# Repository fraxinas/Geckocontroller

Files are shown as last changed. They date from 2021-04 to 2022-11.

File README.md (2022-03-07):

# Geckocontroller

(CC) 2021-2022 by Andreas Frisch <github@fraxinas.dev>

## OwO what's this?
**`geckocontroller` is an ESP32-based all-in-one solution for terrarium automation.**

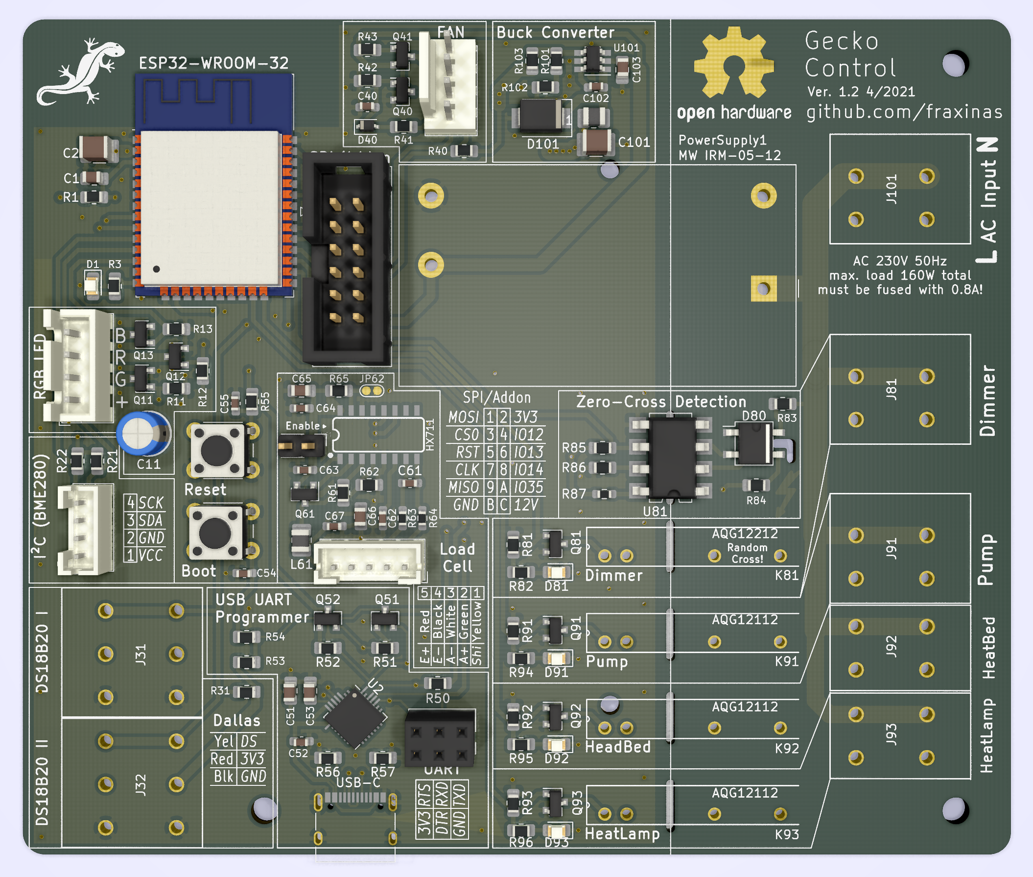
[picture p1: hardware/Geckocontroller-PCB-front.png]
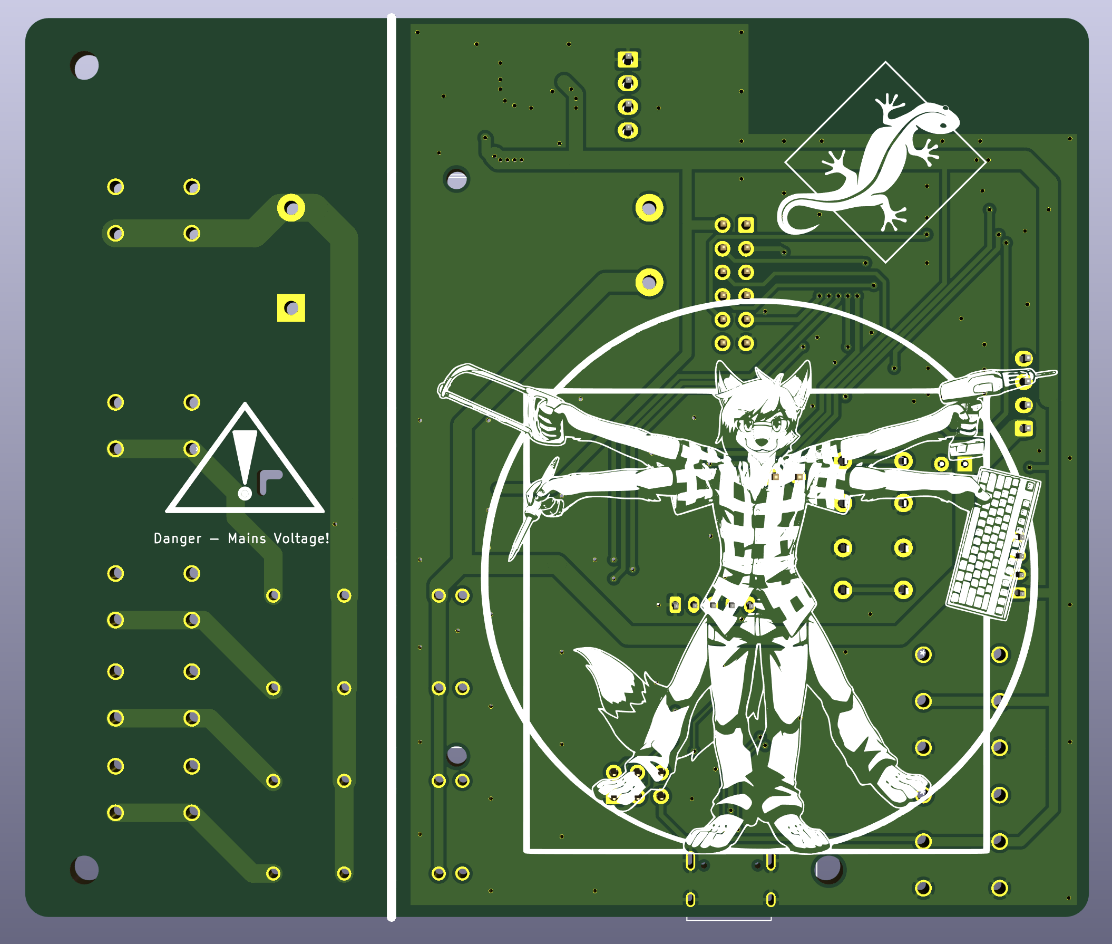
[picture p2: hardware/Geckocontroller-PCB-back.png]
|  |  |
| :--- | :--- |

## Hardware Features
### Relay Output
* 3 solid state relays with zero-cross switching
* individual load 1A each
* for HeatBed (/Fogger), HeatLamp and Pump

### Dimmer Output
* opto-coupler zero cross detection
* random cross solid state relay
* phase controller modulator

### RGB LED Output
* PWM driver
* for 12V RGB LED stripes

### FAN Output
* for an ATX type PC fan
* PWM and tachometer pins
* power cut-off circuitry for completely stopping all types of fans

### Dallas Thermometer Input
* 2 inputs for DS18B20 bus temperature sensors

### I²C Ports
* BME280 Thermo/Hygro/Baro sensor module (ceiling)
* SHT-3xD Thermo/Hygro sensor (ground)

### Load Cell Input
* HX711-based load cell amplifier/ADC
* for weighing / occupancy detection

### USB-C Port
* USB-to-serial programming port

### WiFi
* ESP32 wifi client

### SPI / Addon Connector
* for future extensions like a display or console

### Documentation
* [Circuit Calculations](hardware/calculations/README.md)

## Software

### Using ESPHome.io
* simple YAML configuration for different sensor / actor modules
* Through Home Assistant web interface:
  * data logging and visualization of all environmental readings
  * manually control all actors, modify set points of controllers

### Weather Simulation
* use Nouvelle-Calédonie (Crested Gecko's natural habitat) real weather records
* use temperature, humidity, rain and sky cover values for creating a realistic varied simulation of the habitants' indigenous environment
* simulated sunrise, sunset, lightening storm

### Documentation
* [How-to Setup & Calibrate](software/README.md)

## Console unit
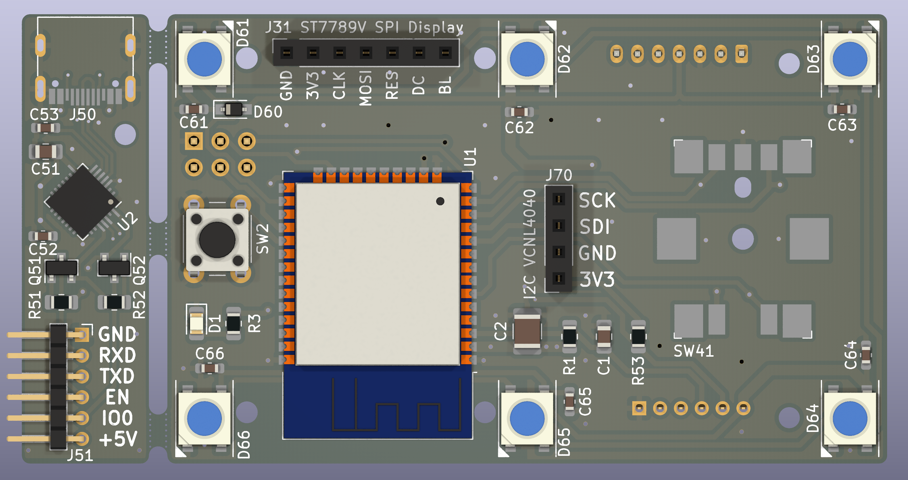
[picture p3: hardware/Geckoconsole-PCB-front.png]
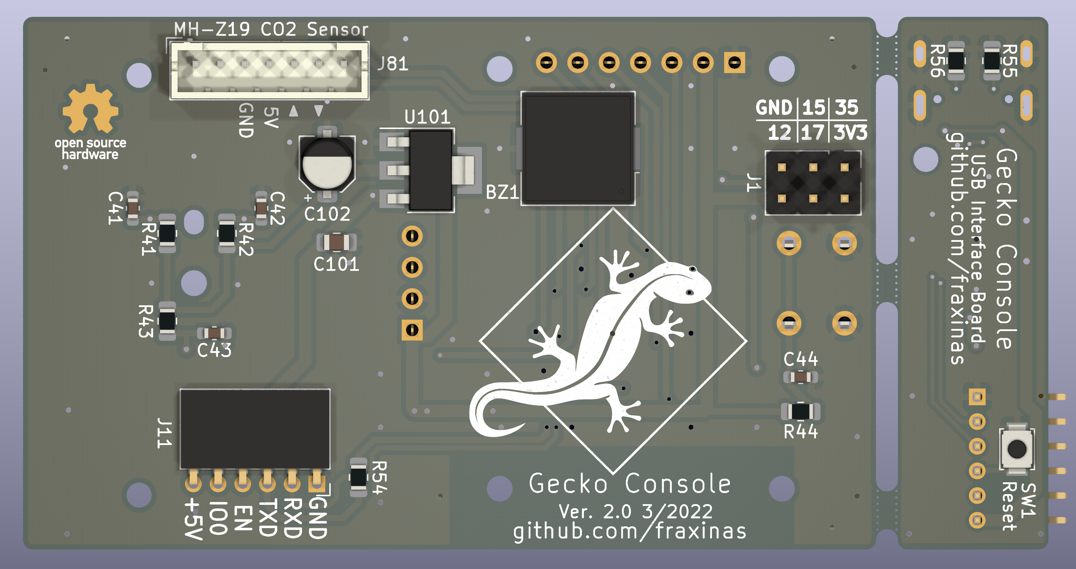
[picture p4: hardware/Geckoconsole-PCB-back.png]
|  |  |
| :--- | :--- |
* Stand-alone device based on ESP32
* remote controls the main unit through home assistant via WiFi
* 240x240 IPS Display
* Rotary encoder + navigation button
* MH-Z19 CO<sub>2</sub> Sensor
* 6x WS2812 addressable RGB LEDs
* Piezo Buzzer for audio alerts
* USB-C powered
* custom esphome components:
  * controls for thermostat, hygrostat, rain, fogger
  * HSV color picker for scenic light

## TODO
### Console unit
- [X] schematic & PCB layout
- [ ] 3d case
- [X] CO2 sensor
- [X] WS2812 RGB LEDs
- [X] buzzer
- [X] software for ST7789 display
- [X] software for rotary encoder
- [ ] VCNL4040 support
- [ ] photos / documentation

### Controller unit
- [x] 3d-printed cases for BME280 sensor and console
- [x] rainfall/humidity automation
- [x] ventilation automation
- [x] moonlight simulation
- [x] thunderstorm simulation
- [ ] photos / documentation

## Project Diary
| Date | Version | Milestone |
| :--- | :--- | :--- |
| 2021-02-21 | v1.0 | Commission of 1st prototype PCB with aisler.net  |
| 2021-03-12 | v1.1 | First time programming of bodged prototype PCB |
| 2021-04-10 | | Fixed hardware issues with [LeoDJ](https://github.com/LeoDJ) & [Patagona](https://github.com/patagonaa) |
| 2021-04-15 | v1.2 | Commission of 2nd revision PCB with aisler.net |
| 2021-05-03 | v1.2 | Completed PCB assembly, all modules working |
| 2021-05-16 | v1.2 | Assembling of case and first deployment of unit  |
| 2022-01-02 | | Added fogger to terrarium |
| 2022-01-09 | | Base weather simulation on real historic records |
| 2022-01-28 | v1.0 | Order Console PCB at aisler.net & parts at LCSC  |
| 2022-02-18 | | Assembled Console PCB |
| 2022-03-07 | v2.0 | New Hardware Revision of Console PCB |

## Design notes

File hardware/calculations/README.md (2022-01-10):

# Geckocontroller Hardware

## Calculations

### ACT4088 Feedback Resistors

with
* V<sub>out</sub> = 3.3V
* R<sub>FB1</sub> chosen 47k

* R<sub>FB2</sub> = R<sub>FB1</sub> / ((V<sub>out</sub> / 0.81) - 1) = 15289.156626506

Values are:
* `R103` = 47k
* `R101` = 15k
* `R102` = 287R

### HX711 Reference Voltage Resistors

with
* AVDD should be 100mV below VCC, so 3.20V
* AVDD = V<sub>BG</sub> * ( R1 + R2 ) / R2
* R1 chosen 47k

Values are:
* `R61` = 47k
* `R62` = 30k1

### FAN PWM integrator switching
* usually PWM fans can't be reliably attenuated to 0 rpm and need to have their Vcc switched in order to turn them off completely
* so to save one extra GPIO output for switching the fan power, this circuit will integrate the PWM signal and simply disconnect the fan's 12V power if the PWM duty cycle is near 0

http://www.falstad.com/circuit/circuitjs.html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

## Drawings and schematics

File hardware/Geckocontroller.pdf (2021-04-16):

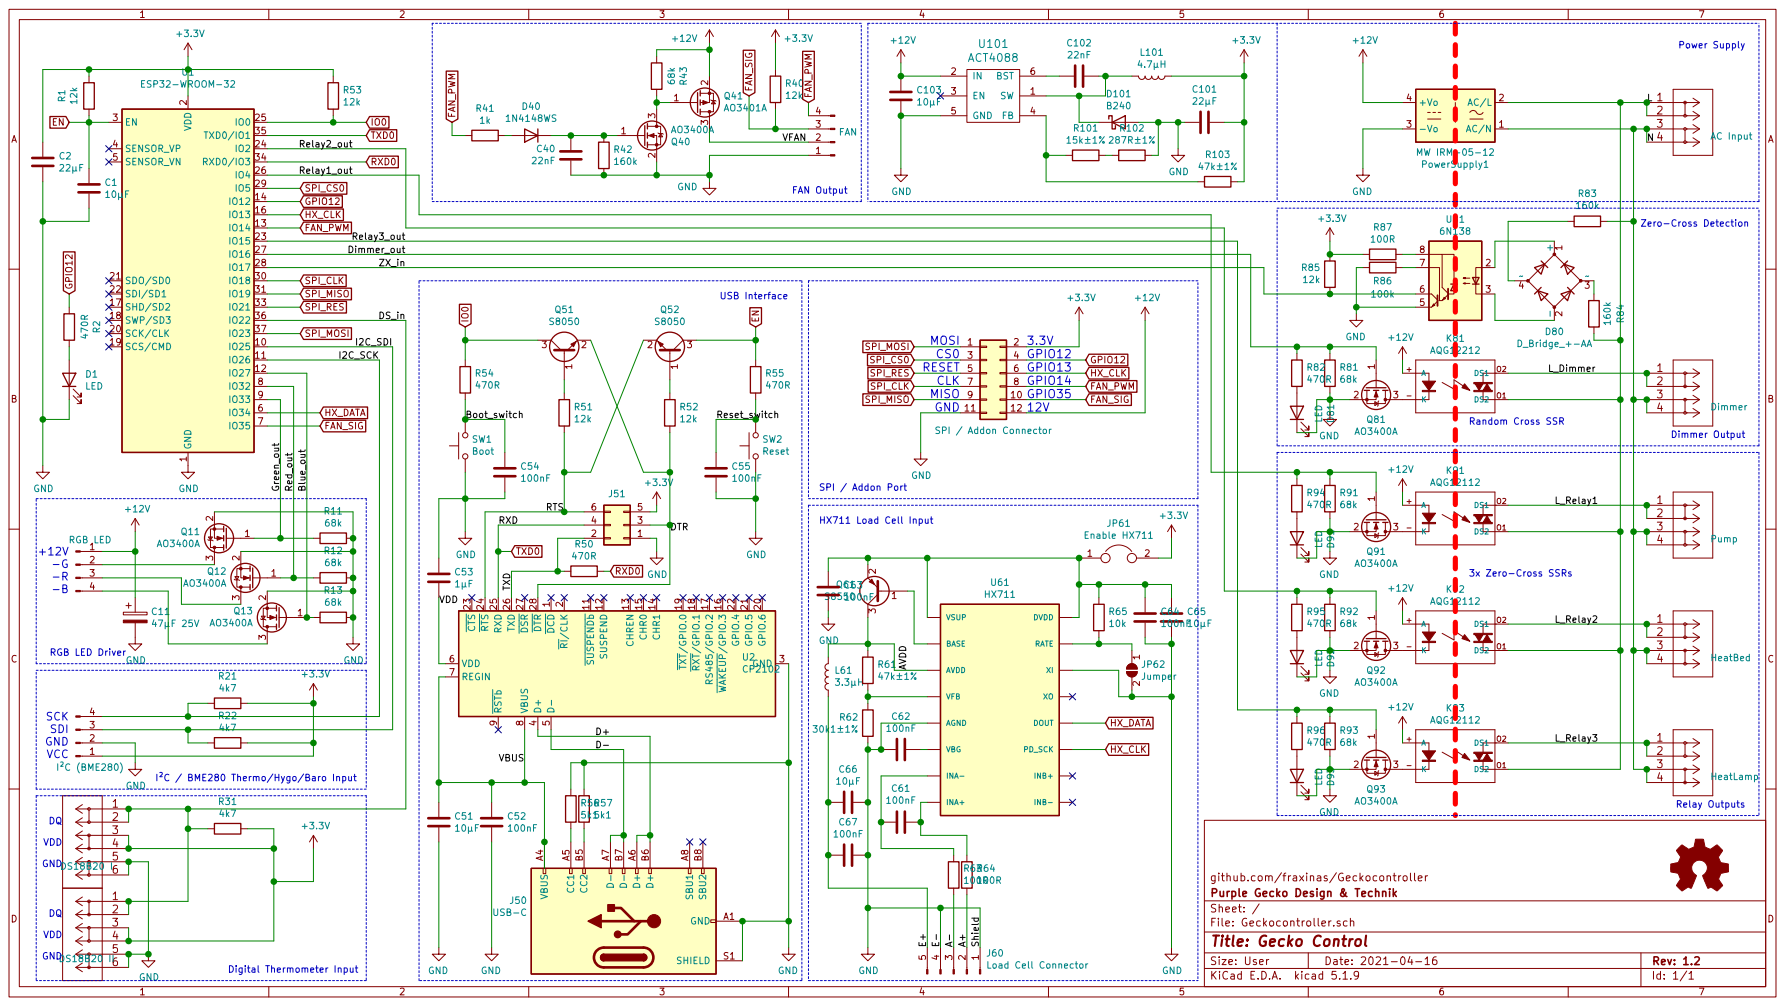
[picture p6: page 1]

2 SCK/CLK 20 SDO/SD0 21 SDI/SD1 22

L_Dimmer Digital Thermometer Input DQ

github.com/fraxinas/Geckocontroller LED D91

Dimmer Output 3x Zero-Cross SSRs

I²C / BME280 Thermo/Hygo/Baro Input +12V

2 GPIO.6 20 GPIO.5 21 GPIO.4 22 CTS 23 RTS 24 RXD 25 TXD 26 DSR 27 DTR 28 GND 3 D+

1 SUSPENDb 11 SUSPEND 12 CHREN 13 CHR1 14 CHR0 15 WAKEUP/GPIO.3 16 RS485/GPIO.2 17 RXT/GPIO.1 18 TXT/GPIO.0 19 RI/CLK

RGB LED Driver SCK

Load Cell Connector AGND

Id: 1/1 Title: Gecko Control File: Geckocontroller.sch Sheet: / Purple Gecko Design & Technik

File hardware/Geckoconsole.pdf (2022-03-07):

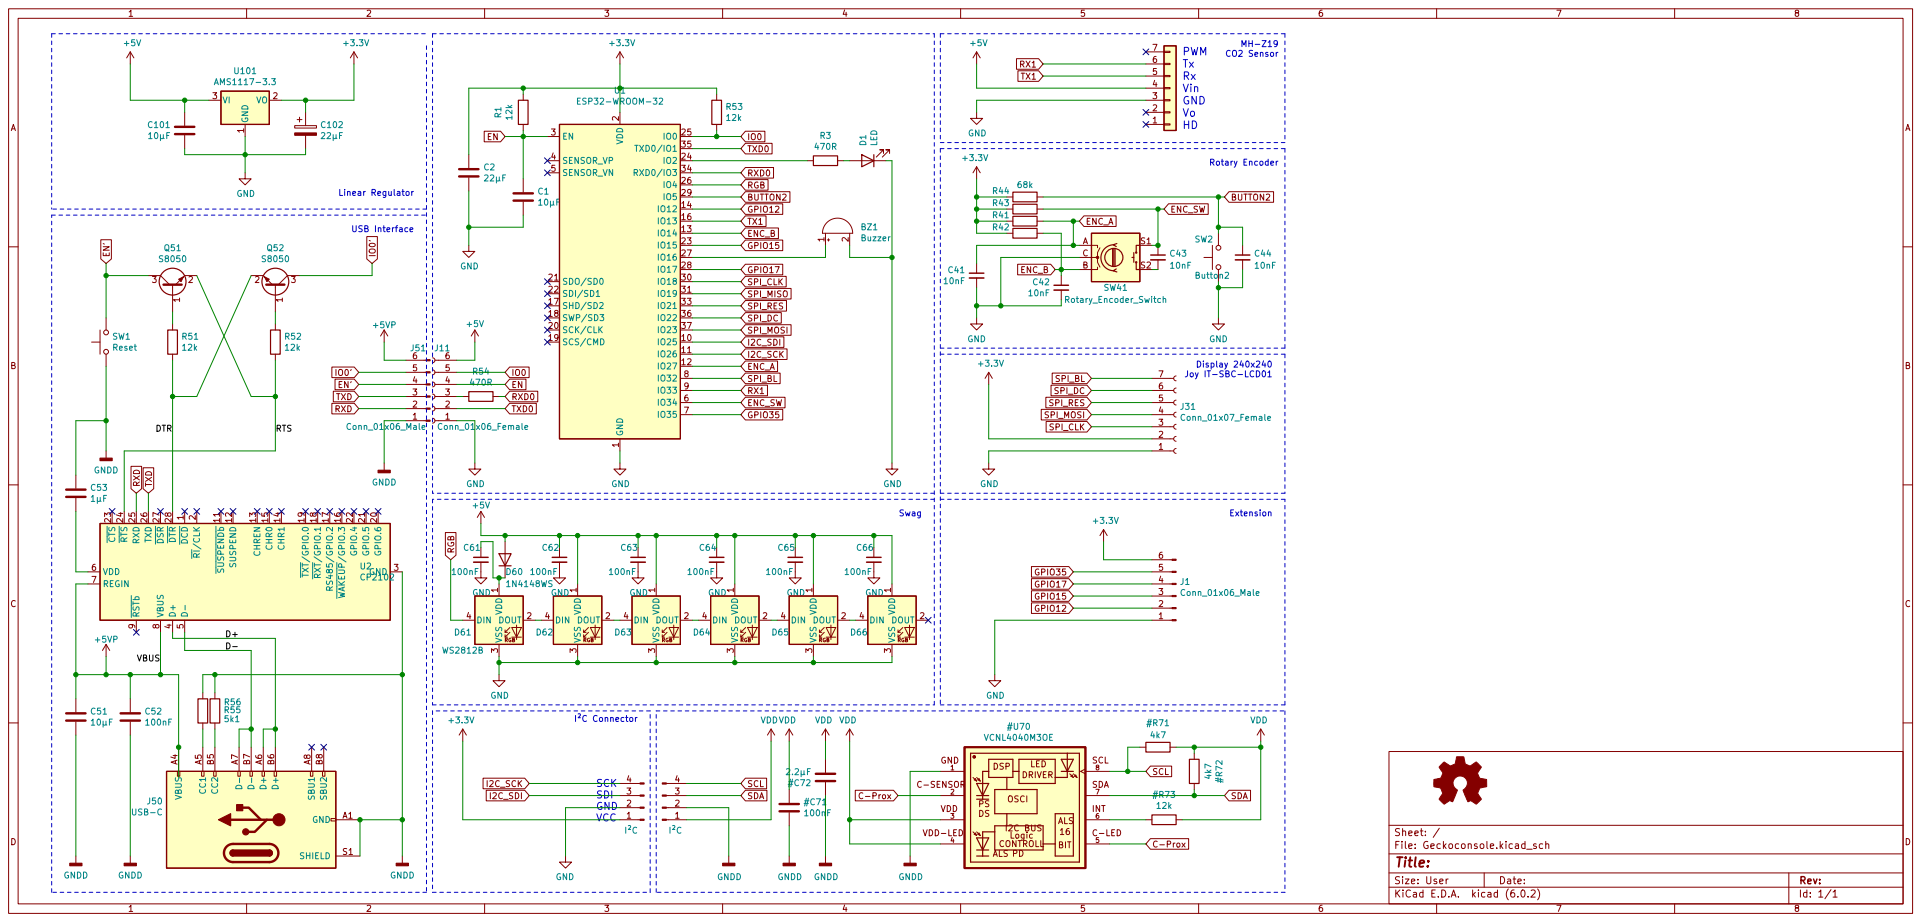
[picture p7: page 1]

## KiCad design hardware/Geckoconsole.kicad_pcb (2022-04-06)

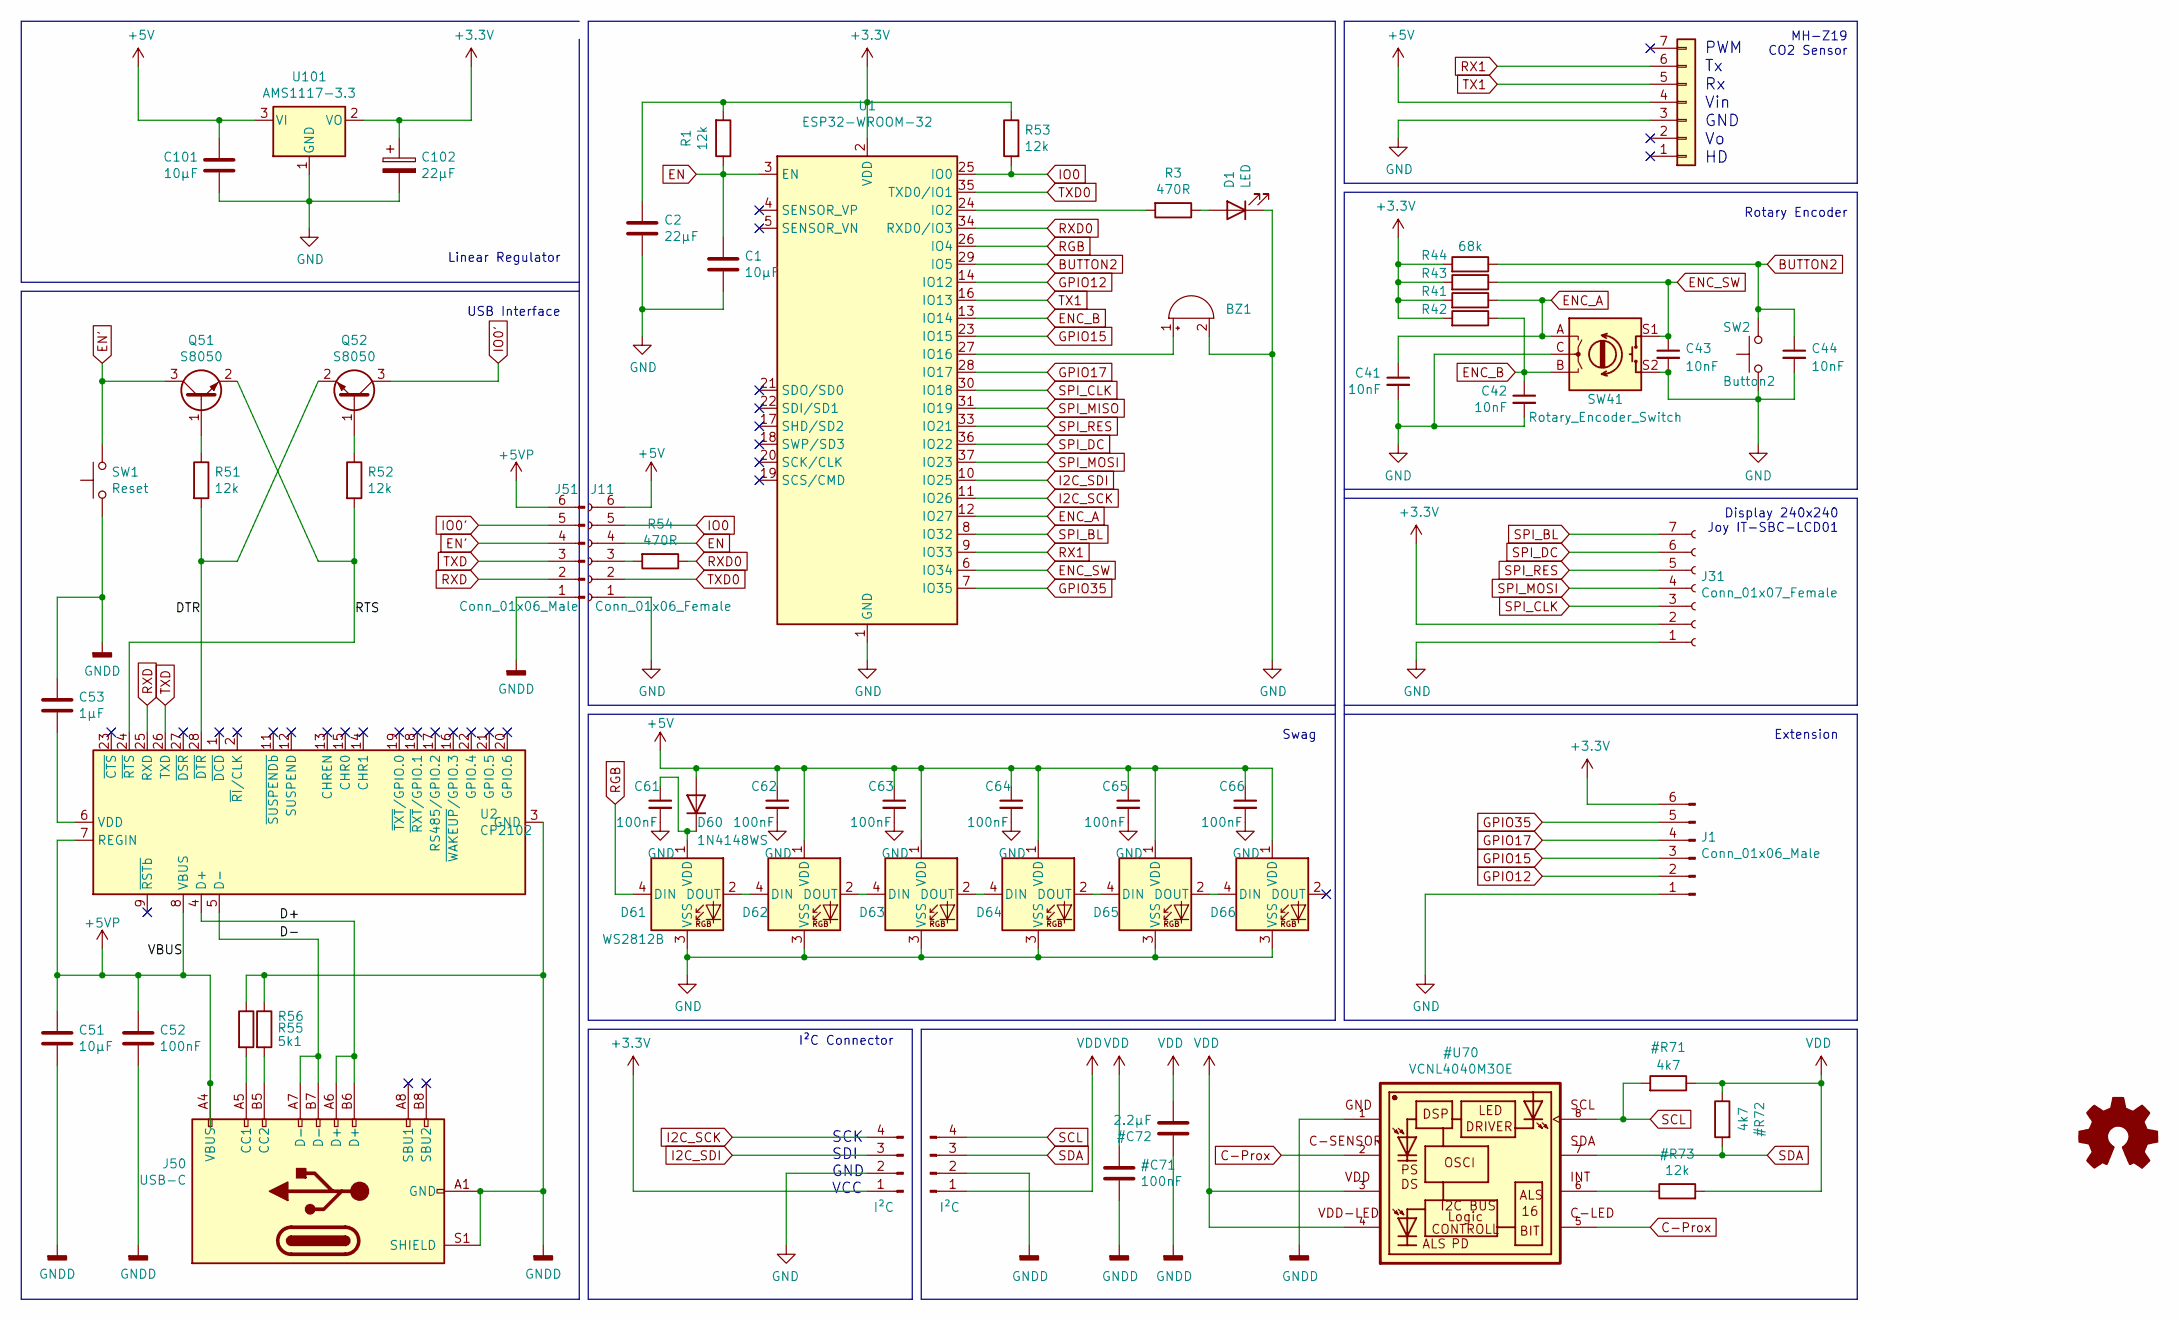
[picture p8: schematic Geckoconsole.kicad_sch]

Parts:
BZ1: (no value)
C1, C51, C101: 10µF; C_0805_2012Metric_Pad1.18x1.45mm_HandSolder
C2: 22µF; C_1210_3225Metric_Pad1.33x2.70mm_HandSolder
C41, C42, C43, C44: 10nF; C_0603_1608Metric_Pad1.08x0.95mm_HandSolder
C52, C61, C62, C63, C64, C65, C66: 100nF; C_0603_1608Metric_Pad1.08x0.95mm_HandSolder
C53: 1µF; C_0603_1608Metric_Pad1.08x0.95mm_HandSolder
C102: 22µF; CP_Elec_4x5.3
D1: LED; LED_0805_2012Metric_Pad1.15x1.40mm_HandSolder
D60: 1N4148WS; D_SOD-323_HandSoldering
D61, D62, D63, D64, D65, D66: WS2812B; LED_WS2812B_PLCC4_5.0x5.0mm_P3.2mm_Marking
J1: Conn_01x06_Male; PinHeader_2x03_P2.54mm_Vertical
J11: Conn_01x06_Female; PinSocket_1x06_P2.00mm_Horizontal
J31: Conn_01x07_Female; PinSocket_1x07_P2.54mm_Vertical
J50: USB-C; USB_C_Receptacle_XKB_U262-16XN-4BVC11
J51: Conn_01x06_Male; PinHeader_1x06_P2.00mm_Horizontal
J70: I²C; PinSocket_1x04_P2.54mm_Vertical
J81: Conn_01x07; JST_PH_B7B-PH-K_1x07_P2.00mm_Vertical
LOGO1: Logo_Open_Hardware_Small; OSHW-Logo_5.7x6mm_Mask
Q51, Q52: S8050; SOT-23
R1, R51, R52, R53: 12k; R_0805_2012Metric_Pad1.20x1.40mm_HandSolder
R3, R54: 470R; R_0805_2012Metric_Pad1.20x1.40mm_HandSolder
R41, R42, R43, R44: 68k; R_0805_2012Metric_Pad1.20x1.40mm_HandSolder
R55, R56: 5k1; R_0805_2012Metric_Pad1.20x1.40mm_HandSolder
SW1: Reset; SW_SPST_B3U-1000P-B
SW2: Button2; SW_PUSH_6mm_H5mm
SW41: Rotary_Encoder_Switch; Rotary_Encoder_Switched_PEC11R
U1: ESP32-WROOM-32
U2: CP2102; CP2102-QFN-28-modified
U101: AMS1117-3.3; SOT-223-3_TabPin2

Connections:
+3V3: C2.1, C102.1, J1.6, J31.2, J70.1, R1.2, R41.2, R42.2, R43.2, R44.2, R53.1, U1.2 (VDD), U101.2 (VO)
+5V: C62.1, C63.1, C64.1, C65.1, C66.1, C101.1, D60.2 (A), D62.1 (VDD), D63.1 (VDD), D64.1 (VDD), D65.1 (VDD), D66.1 (VDD), J11.6, J81.4, U101.3 (VI)
+5VP: C51.1, C52.1, J50.A4 (VBUS), J50.A9 (VBUS), J50.B4 (VBUS), J50.B9 (VBUS), J51.6, U2.7 (REGIN), U2.8 (VBUS)
/D+: J50.A6 (D+), J50.B6 (D+), U2.4 (D+)
/D-: J50.A7 (D-), J50.B7 (D-), U2.5 (D-)
/DTR: Q52.2 (E), R51.2, U2.28 (~DTR)
/RTS: Q51.2 (E), R52.2, U2.24 (~RTS)
BUTTON2: C44.1, R44.1, SW2.2, U1.29 (IO5)
EN: C1.1, J11.4, R1.1, U1.3 (EN)
EN': J51.4, Q51.3 (C), SW1.2
ENC_A: C41.1, R41.1, SW41.A, U1.12 (IO27)
ENC_B: C42.1, R42.1, SW41.B, U1.13 (IO14)
ENC_SW: C43.1, R43.1, SW41.S1, U1.6 (IO34)
GND: BZ1.2 (+), C1.2, C2.2, C41.2, C42.2, C43.2, C44.2, C61.2, C62.2, C63.2, C64.2, C65.2, C66.2, C101.2, C102.2, D1.1 (K), D61.3 (VSS), D62.3 (VSS), D63.3 (VSS), D64.3 (VSS), D65.3 (VSS), D66.3 (VSS), J1.1, J11.1, J31.1, J70.2, J81.3, SW2.1, SW41.C, SW41.S2, U1.1 (GND), U1.15 (GND), U1.38 (GND), U1.39 (GND), U101.1 (GND)
GPIO12: J1.2, U1.14 (IO12)
GPIO15: J1.3, U1.23 (IO15)
GPIO17: J1.4, U1.28 (IO17)
GPIO35: J1.5, U1.7 (IO35)
I2C_SCK: J70.4, U1.11 (IO26)
I2C_SDI: J70.3, U1.10 (IO25)
IO0: J11.5, R53.2, U1.25 (IO0)
IO0': J51.5, Q52.3 (C)
unnamed: BZ1.1 (-), U1.27 (IO16)
unnamed: C53.2, U2.6 (VDD)
unnamed: C61.1, D60.1 (K), D61.1 (VDD)
unnamed: D1.2 (A), R3.1
unnamed: D61.2 (DOUT), D62.4 (DIN)
unnamed: D62.2 (DOUT), D63.4 (DIN)
unnamed: D63.2 (DOUT), D64.4 (DIN)
unnamed: D64.2 (DOUT), D65.4 (DIN)
unnamed: D65.2 (DOUT), D66.4 (DIN)
unnamed: J11.3, R54.2
unnamed: J50.A5 (CC1), R56.2
unnamed: J50.B5 (CC2), R55.2
unnamed: Q51.1 (B), R51.1
unnamed: Q52.1 (B), R52.1
unnamed: R3.2, U1.24 (IO2)
RGB: D61.4 (DIN), U1.26 (IO4)
RX1: J81.6, U1.9 (IO33)
RXD: J51.2, U2.25 (RXD)
RXD0: R54.1, U1.34 (RXD0/IO3)
SPI_BL: J31.7, U1.8 (IO32)
SPI_CLK: J31.3, U1.30 (IO18)
SPI_DC: J31.6, U1.36 (IO22)
SPI_MISO: U1.31 (IO19)
SPI_MOSI: J31.4, U1.37 (IO23)
SPI_RES: J31.5, U1.33 (IO21)
TX1: J81.5, U1.16 (IO13)
TXD: J51.3, U2.26 (TXD)
TXD0: J11.2, U1.35 (TXD0/IO1)

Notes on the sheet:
Display 240x240 Joy IT-SBC-LCD01
USB Interface
SCK SDI GND VCC
Linear Regulator
PWM Tx Rx Vin GND Vo HD
Rotary Encoder
I²C Connector
Swag
MH-Z19 CO2 Sensor
Extension

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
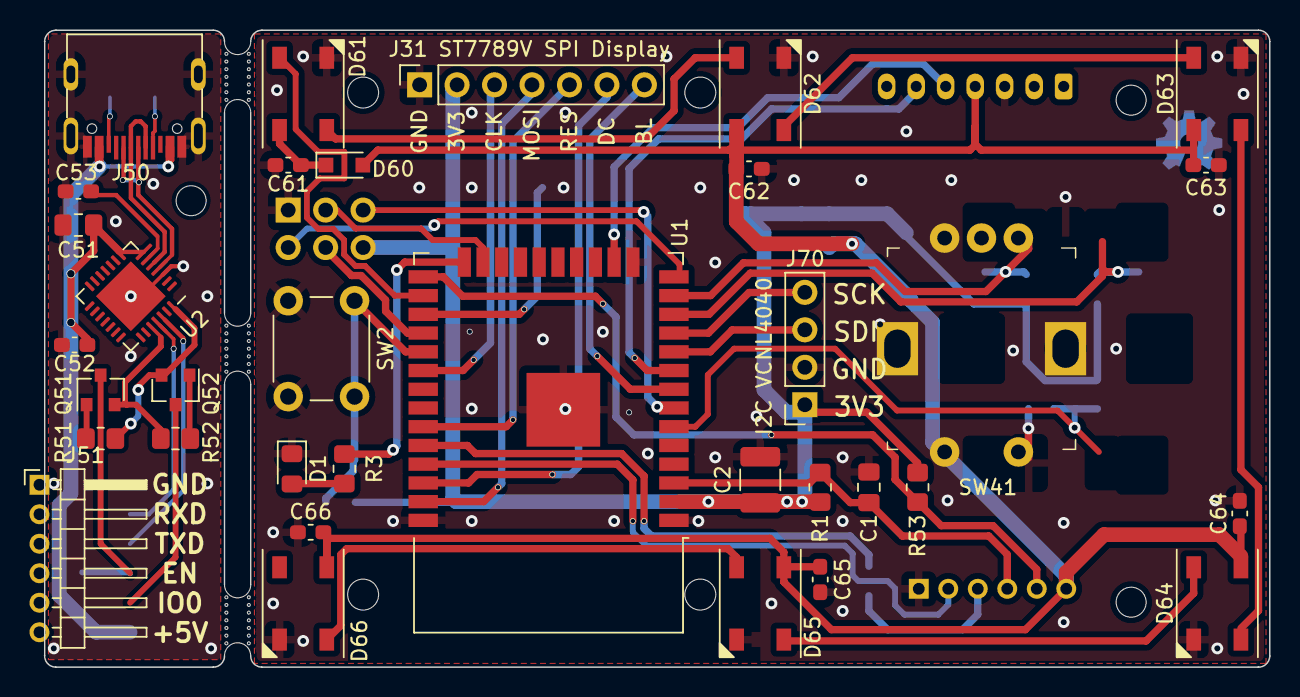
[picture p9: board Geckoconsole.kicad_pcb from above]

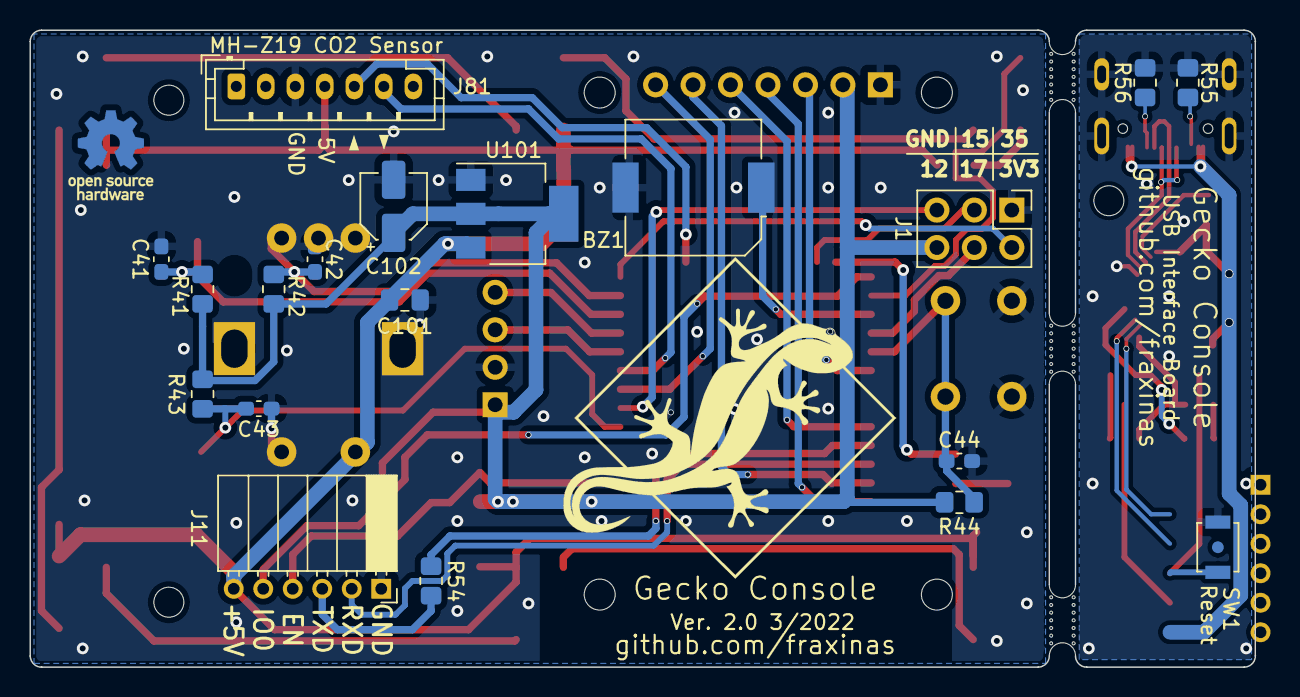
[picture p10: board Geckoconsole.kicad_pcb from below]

Board: 2 copper layers, 83.1 x 43.2 mm, 54 parts (20 on the bottom side), 50 nets.

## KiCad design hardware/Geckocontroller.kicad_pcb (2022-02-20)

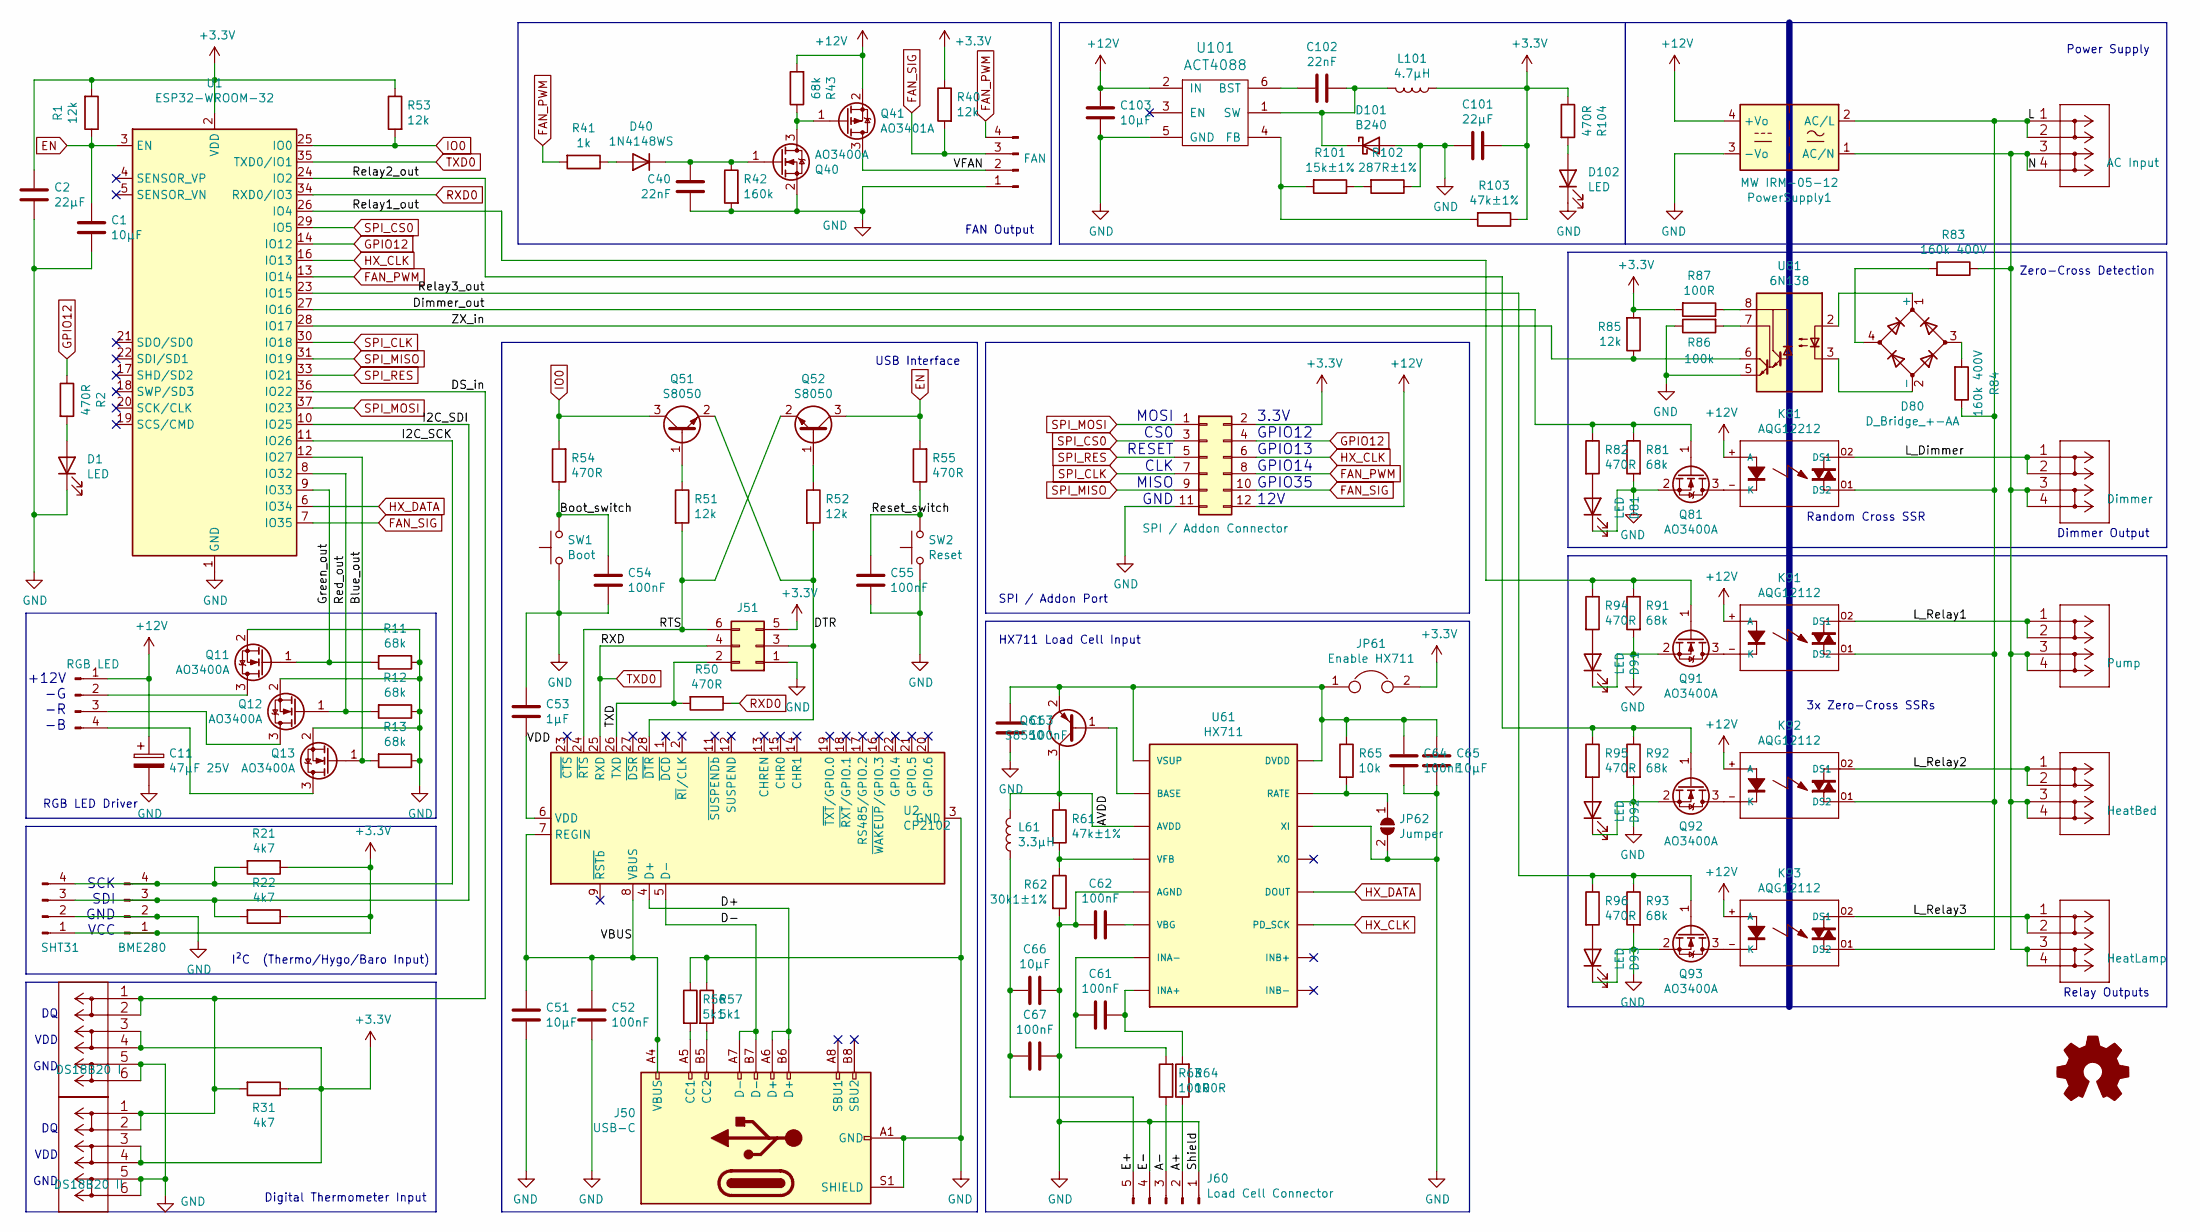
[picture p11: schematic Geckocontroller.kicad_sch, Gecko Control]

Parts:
C1, C51, C65, C66, C103: 10µF; C_0805_2012Metric_Pad1.18x1.45mm_HandSolder
C2, C101: 22µF; C_1210_3225Metric_Pad1.33x2.70mm_HandSolder
C11: 47µF 25V; CP_Radial_D5.0mm_P2.50mm
C40, C102: 22nF; C_0603_1608Metric_Pad1.08x0.95mm_HandSolder
C52, C54, C55, C61, C62, C63, C64, C67: 100nF; C_0603_1608Metric_Pad1.08x0.95mm_HandSolder
C53: 1µF; C_0805_2012Metric_Pad1.18x1.45mm_HandSolder
D1, D81, D91, D92, D93, D102: LED; LED_0805_2012Metric_Pad1.15x1.40mm_HandSolder
D40: 1N4148WS; D_SOD-323_HandSoldering
D80: D_Bridge_+-AA; TO-269AA
D101: B240; D_SMB
J1: SHT31; JST_PH_B4B-PH-K_1x04_P2.00mm_Vertical
J11: RGB LED; JST_XH_B4B-XH-A_1x04_P2.50mm_Vertical
J21: BME280; JST_PH_B4B-PH-K_1x04_P2.00mm_Vertical
J31: DS18B20 I; WAGO-2604-1103-bare
J32: DS18B20 II; WAGO-2604-1103-bare
J40: FAN; Molex_KK-254_AE-6410-04A_1x04_P2.54mm_Vertical
J50: USB-C; USB_C_Receptacle_XKB_U262-16XN-4BVC11
J51: UART; PinSocket_2x03_P2.54mm_Vertical
J60: Load Cell Connector; JST_PH_B5B-PH-K_1x05_P2.00mm_Vertical
J70: SPI / Addon Connector; IDC-Header_2x06_P2.54mm_Vertical
J81: Dimmer; WAGO-2604-1102
J91: Pump; WAGO-2604-1102
J92: HeatBed; WAGO-2604-1102-bare
J93: HeatLamp; WAGO-2604-1102-bare
J101: AC Input; WAGO-2604-1102
JP61: Enable HX711; PinHeader_1x02_P2.54mm_Vertical
JP62: Jumper; SolderJumper-2_Open_Mini
K81: AQG12212; AQG22224
K91, K92, K93: AQG12112; AQG22224
L61: 3.3µH; L_1008_2520Metric_Pad1.43x2.20mm_HandSolder
L101: 4.7µH; L_1008_2520Metric_Pad1.43x2.20mm_HandSolder
LOGO1: Logo_Open_Hardware_Small; OSHW-Logo2_14.6x12mm_Mask
PowerSupply1: MW IRM-05-12; Converter_ACDC_MeanWell_IRM-05-xx_THT
Q11, Q12, Q13, Q40, Q81, Q91, Q92, Q93: AO3400A; SOT-23
Q41: AO3401A; SOT-23
Q51, Q52: S8050; SOT-23
Q61: S8550; SOT-23
R1, R40, R51, R52, R53, R85: 12k; R_0805_2012Metric_Pad1.20x1.40mm_HandSolder
R2, R50, R54, R55, R82, R94, R95, R96, R104: 470R; R_0805_2012Metric_Pad1.20x1.40mm_HandSolder
R11, R12, R13, R43, R81, R91, R92, R93: 68k; R_0805_2012Metric_Pad1.20x1.40mm_HandSolder
R21, R22, R31: 4k7; R_0805_2012Metric_Pad1.20x1.40mm_HandSolder
R41: 1k; R_0805_2012Metric_Pad1.20x1.40mm_HandSolder
R42: 160k; R_0805_2012Metric_Pad1.20x1.40mm_HandSolder
R56, R57: 5k1; R_0805_2012Metric_Pad1.20x1.40mm_HandSolder
R61, R103: 47k±1%; R_0805_2012Metric_Pad1.20x1.40mm_HandSolder
R62: 30k1±1%; R_0805_2012Metric_Pad1.20x1.40mm_HandSolder
R63, R64, R87: 100R; R_0603_1608Metric_Pad0.98x0.95mm_HandSolder
R65: 10k; R_0805_2012Metric_Pad1.20x1.40mm_HandSolder
R83, R84: 160k 400V; R_1206_3216Metric_Pad1.30x1.75mm_HandSolder
R86: 100k; R_0805_2012Metric_Pad1.20x1.40mm_HandSolder
R101: 15k±1%; R_0805_2012Metric_Pad1.20x1.40mm_HandSolder
R102: 287R±1%; R_0805_2012Metric_Pad1.20x1.40mm_HandSolder
SW1: Boot; SW_PUSH_6mm
SW2: Reset; SW_PUSH_6mm
U1: ESP32-WROOM-32
U2: CP2102; CP2102-QFN-28-modified
U61: HX711; SO16
U81: 6N138; SMDIP-8_W9.53mm
U101: ACT4088; SOT-23-6_Handsoldering

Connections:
+3V3: C2.1, C101.1, J1.1, J21.1, J31.3, J31.4, J32.3, J32.4, J51.5, J70.2, JP61.2, L101.1, R1.2, R21.1, R22.1, R31.1, R40.1, R53.1, R85.2, R87.2, R103.1, R104.1, U1.2 (VDD)
+12V: C11.1, C103.1, J11.1, J70.12, K81.+ (A), K91.+ (A), K92.+ (A), K93.+ (A), PowerSupply1.4 (+Vo), Q41.2 (S), R43.2, U101.2 (IN)
/A+: J60.2, R64.1
/A-: J60.3, R63.1
/AVDD: L61.2, Q61.3 (C), R61.1, U61.3 (AVDD)
/Blue_out: Q13.1 (G), R13.2, U1.12 (IO27)
/Boot_switch: C54.1, R54.1, SW1.2
/D+: J50.A6 (D+), J50.B6 (D+), U2.4 (D+)
/D-: J50.A7 (D-), J50.B7 (D-), U2.5 (D-)
/DS_in: J31.1, J31.2, J32.1, J32.2, R31.2, U1.36 (IO22)
/DTR: J51.3, Q51.2 (E), R52.2, U2.28 (~DTR)
/Dimmer_out: Q81.1 (G), R81.1, R82.1, U1.27 (IO16)
/E+: C66.2, C67.2, J60.5, L61.1
/Green_out: Q11.1 (G), R11.2, U1.9 (IO33)
/I2C_SCK: J1.4, J21.4, R21.2, U1.11 (IO26)
/I2C_SDI: J1.3, J21.3, R22.2, U1.10 (IO25)
/L: J101.1, J101.2, K81.O1 (DS2), K91.O1 (DS2), K92.O1 (DS2), K93.O1 (DS2), PowerSupply1.2 (AC/L), R84.1
/L_Dimmer: J81.1, J81.2, K81.O2 (DS1)
/L_Relay1: J91.1, J91.2, K91.O2 (DS1)
/L_Relay2: J92.1, J92.2, K92.O2 (DS1)
/L_Relay3: J93.1, J93.2, K93.O2 (DS1)
/N: J81.3, J81.4, J91.3, J91.4, J92.3, J92.4, J93.3, J93.4, J101.3, J101.4, PowerSupply1.1 (AC/N), R83.1
/RTS: J51.6, Q52.2 (E), R51.2, U2.24 (~RTS)
/Red_out: Q12.1 (G), R12.2, U1.8 (IO32)
/Relay1_out: Q91.1 (G), R91.1, R94.1, U1.26 (IO4)
/Relay2_out: Q92.1 (G), R92.1, R95.1, U1.24 (IO2)
/Relay3_out: Q93.1 (G), R93.1, R96.1, U1.23 (IO15)
/Reset_switch: C55.1, R55.1, SW2.2
/TXD: J51.2, R50.2, U2.26 (TXD)
/VBUS: C51.1, C52.1, J50.A4 (VBUS), J50.A9 (VBUS), J50.B4 (VBUS), J50.B9 (VBUS), U2.7 (REGIN), U2.8 (VBUS)
/VDD: C53.2, U2.6 (VDD)
/VFAN: J40.2, Q41.3 (D)
/ZX_in: R85.1, U1.28 (IO17), U81.6 (VO2)
EN: C1.1, Q52.3 (C), R1.1, R55.2, U1.3 (EN)
FAN_PWM: J40.4, J70.8, R41.2, U1.13 (IO14)
FAN_SIG: J40.3, J70.10, R40.2, U1.7 (IO35)
GND: C1.2, C2.2, C11.2, C40.1, C51.2, C52.2, C53.1, C54.2, C55.2, C62.2, C63.2, C64.2, C65.2, C66.1, C67.1, C101.2, C103.2, D1.1 (K), D81.1 (K), D91.1 (K), D92.1 (K), D93.1 (K), D101.2 (A), D102.1 (K), J1.2, J21.2, J31.5, J31.6, J32.5, J32.6, J40.1, J50.A1 (GND), J50.A12 (GND), J50.B1 (GND), J50.B12 (GND), J50.S1 (SHIELD), J51.1, J60.1, J60.4, J70.11, JP62.2 (B), PowerSupply1.3 (-Vo), Q11.2 (S), Q12.2 (S), Q13.2 (S), Q40.2 (S), Q81.2 (S), Q91.2 (S), Q92.2 (S), Q93.2 (S), R11.1, R12.1, R13.1, R42.2, R56.1, R57.1, R62.2, R81.2, R86.1, R91.2, R92.2, R93.2, R102.1, SW1.1, SW2.1, U1.1 (GND), U1.15 (GND), U1.38 (GND), U1.39 (GND), U2.3 (GND), U2.29 (GND), U61.5 (AGND), U61.14 (XI), U81.5 (GND), U101.5 (GND)
GPIO12: J70.4, R2.1, U1.14 (IO12)
HX_CLK: J70.6, U1.16 (IO13), U61.11 (PD_SCK)
HX_DATA: U1.6 (IO34), U61.12 (DOUT)
IO0: Q51.3 (C), R53.2, R54.2, U1.25 (IO0)
unnamed: C40.2, D40.1 (K), Q40.1 (G), R42.1
unnamed: C61.1, R63.2, U61.7 (INA-)
unnamed: C61.2, R64.2, U61.8 (INA+)
unnamed: C62.1, U61.6 (VBG)
unnamed: C63.1, C64.1, C65.1, JP61.1, Q61.2 (E), R65.1, U61.1 (VSUP), U61.16 (DVDD)
unnamed: C102.1, D101.1 (K), L101.2, U101.1 (SW)
unnamed: C102.2, U101.6 (BST)
unnamed: D1.2 (A), R2.2
unnamed: D40.2 (A), R41.1
unnamed: D80.1 (+), U81.2 (C1)
unnamed: D80.2 (-), U81.3 (C2)
unnamed: D80.3, R84.2
unnamed: D80.4, R83.2
unnamed: D81.2 (A), R82.2
unnamed: D91.2 (A), R94.2
unnamed: D92.2 (A), R95.2
unnamed: D93.2 (A), R96.2
unnamed: D102.2 (A), R104.2
unnamed: J11.2, Q11.3 (D)
unnamed: J11.3, Q12.3 (D)
unnamed: J11.4, Q13.3 (D)
unnamed: J50.A5 (CC1), R56.2
unnamed: J50.B5 (CC2), R57.2
unnamed: JP62.1 (A), R65.2, U61.15 (RATE)
unnamed: K81.- (K), Q81.3 (D)
unnamed: K91.- (K), Q91.3 (D)
unnamed: K92.- (K), Q92.3 (D)
unnamed: K93.- (K), Q93.3 (D)
unnamed: Q40.3 (D), Q41.1 (G), R43.1
unnamed: Q51.1 (B), R51.1
unnamed: Q52.1 (B), R52.1
unnamed: Q61.1 (B), U61.2 (BASE)
unnamed: R61.2, R62.1, U61.4 (VFB)
unnamed: R86.2, U81.7 (VO1)
unnamed: R87.1, U81.8 (VCC)
unnamed: R101.1, R102.2
unnamed: R101.2, R103.2, U101.4 (FB)
RXD0: R50.1, U1.34 (RXD0/IO3)
SPI_CLK: J70.7, U1.30 (IO18)
SPI_CS0: J70.3, U1.29 (IO5)
SPI_MISO: J70.9, U1.31 (IO19)
SPI_MOSI: J70.1, U1.37 (IO23)
SPI_RES: J70.5, U1.33 (IO21)
TXD0: J51.4, U1.35 (TXD0/IO1), U2.25 (RXD)

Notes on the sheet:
Relay Outputs
SCK SDI GND VCC
FAN Output
HX711 Load Cell Input
I²C (Thermo/Hygo/Baro Input)
MOSI CS0 RESET CLK MISO GND
DQ VDD GND
SPI / Addon Port
RGB LED Driver
3.3V GPIO12 GPIO13 GPIO14 GPIO35 12V
3x Zero-Cross SSRs
Digital Thermometer Input
Power Supply
Dimmer Output
Zero-Cross Detection
+12V -G -R -B
USB Interface
Random Cross SSR

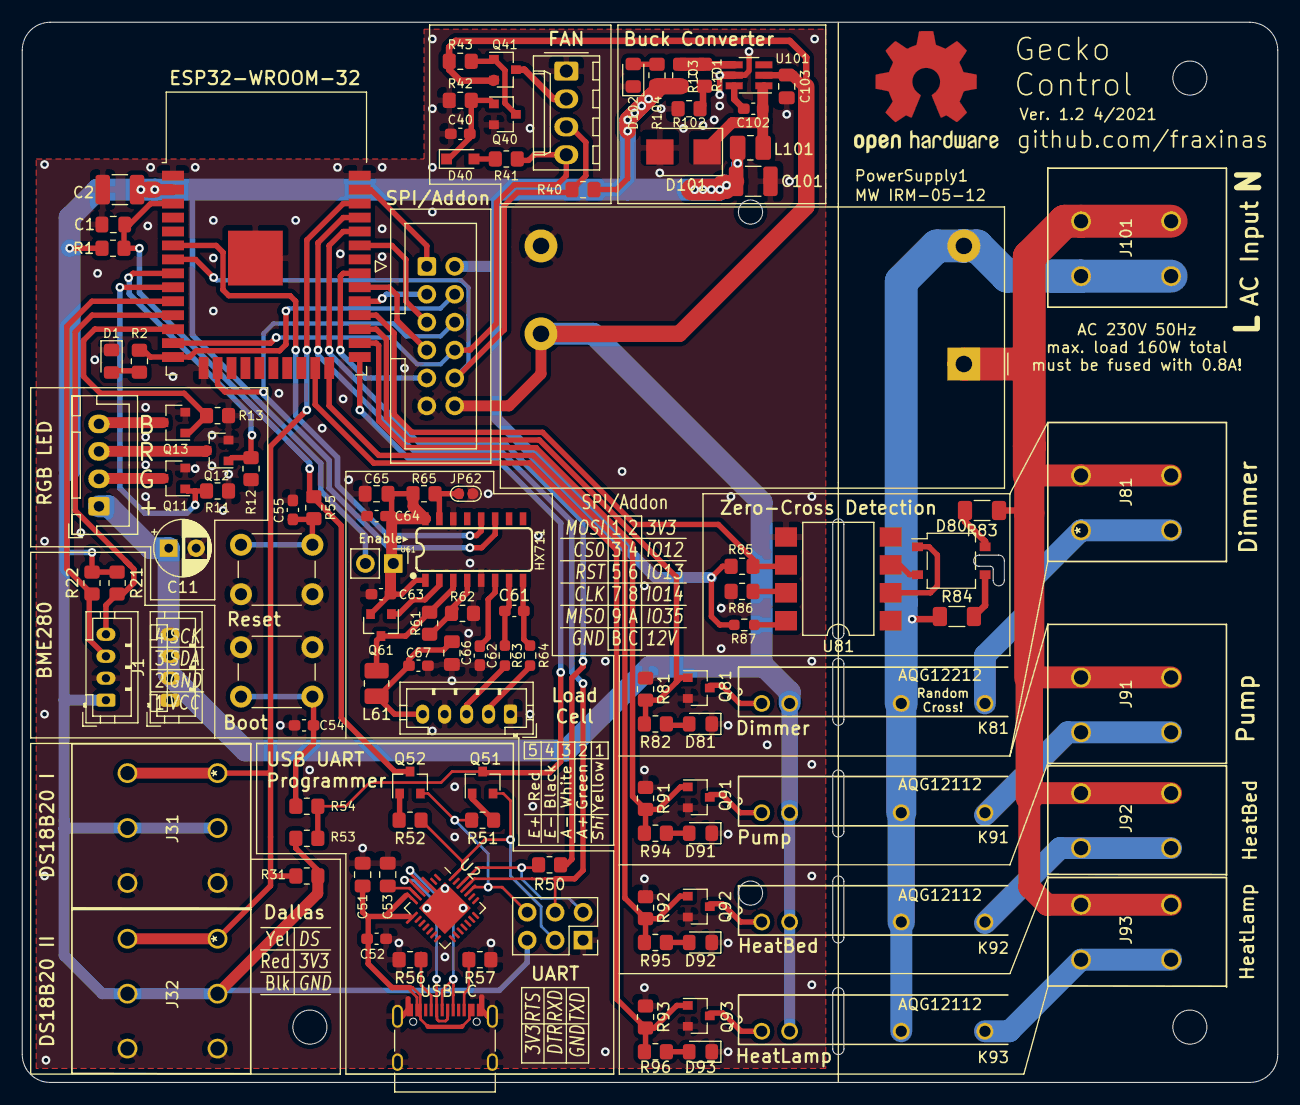
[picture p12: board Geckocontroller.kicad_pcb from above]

Board: 2 copper layers, 114.3 x 96.5 mm, 114 parts (0 on the bottom side), 85 nets.

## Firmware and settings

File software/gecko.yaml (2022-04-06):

esphome:
  name: geckocontrol
  platform: ESP32
  board: nodemcu-32s
  includes:
    - gecko_custom.h

external_components:
  - source:
      type: local
      path: custom_components

wifi:
  ssid: !secret wifi_ssid
  password: !secret wifi_password

  # Enable fallback hotspot (captive portal) in case wifi connection fails
  ap:
    ssid: "Geckocontrol Fallback Hotspot"
    password: !secret fallback_password

#captive_portal:

# Enable logging
logger:
  level: DEBUG

# Enable Home Assistant API
api:
  services:
    - service: control_twilight_attenuation
      variables:
        level: float
      then:
        - output.set_level:
            id: daylight_attenuation_output
            level: !lambda 'return level / 100.0;'
ota:

custom_component:
- lambda: |-
    auto gecko_custom = new GeckoCustomComponent();
    return {gecko_custom};
  components:
    - id: gecko

switch:
  - platform: template
    name: "Nighttime / Daytime"
    icon: mdi:theme-light-dark
    lambda: |-
      return id(is_daytime);
    turn_on_action:
      - lambda: |-
          id(is_daytime) = true;
    turn_off_action:
      - lambda: |-
          id(is_daytime) = false;

button:
  - platform: template
    id: pump_button
    name: "Let it rain"
    icon: "mdi:weather-rainy"
    on_press:
      - output.turn_on:
          id: rain_pump
      - delay: 4s
      - output.turn_off:
          id: rain_pump

  - platform: template
    id: fog_button
    name: "Sleepy hollow"
    icon: "mdi:weather-fog"
    on_press:
      - output.set_level:
            id: fogger_float
            level: 1.0
      - delay: 30s
      - output.set_level:
            id: fogger_float
            level: 0.0

output:
  - platform: ac_dimmer
    id: dimmer1
    gate_pin: 16
    min_power: 15%
    zero_cross_pin:
      number: 17
      mode: INPUT
      inverted: no
  - platform: slow_pwm
    pin: 15
    id: heat_lamp_pwm
    period: 1min
  - platform: gpio
    pin: 4
    id: rain_pump
  - platform: slow_pwm
    pin: 2
    id: fogger_float
    period: 60s
  - platform: ledc
    pin: 32
    id: component_red
    channel: 0
  - platform: ledc
    pin: 33
    id: component_green
    channel: 2
  - platform: ledc
    pin: 27
    id: component_blue
    channel: 4
  - platform: ledc
    pin: GPIO14
    id: fan_pwm
    frequency: 25000 hz
    channel: 7
  - platform: custom
    type: float
    lambda: |-
      auto rain_pump_output_c = new RainPumpOutput();
      App.register_component(rain_pump_output_c);
      return {rain_pump_output_c};
    outputs:
      id: rain_pump_float
      #period: 30min
      max_power: 0.02
      # max. 18 seconds of rain per half hour
  - platform: template
    id: daylight_attenuation_output
    type: float
    write_action:
      - lambda: |-
          id(twilight_attenuation) = state;
          ESP_LOGD(TAG, "wrote twilight_attenuation: %.2f", id(twilight_attenuation));
  - platform: template
    id: fogger_humidifier
    type: float
    write_action:
      - lambda: |-
            ClimateAction action = id(hygrostat).action;
            if (action == CLIMATE_ACTION_HEATING) {
              float duty_cycle = state/4.0;
              ESP_LOGD(TAG, "Hygrostat PID Controller fogger write_action: %.3f / duty cycle: %.0f%%", state, duty_cycle*100);
              id(fogger_float).set_level(duty_cycle);
            } else {
              ESP_LOGD(TAG, "Hygrostat PID Controller turn off fogger");
            }
  - platform: template
    id: heater
    type: float
    write_action:
      - lambda: |-
            ClimateMode mode = id(thermostat_air).mode;
            if (mode == CLIMATE_MODE_OFF) {
                ESP_LOGD(TAG, "ignored heater write_action because thermostat is off");
            } else if (id(is_daytime) == true) {
              auto therm = id(thermostat_air).make_call();
              float set_val = id(thermostat_air)->get_output_value();
              float att_max = id(twilight_attenuation)*id(skycond_attenuation);
              float att_min = att_max/10.0;
              ESP_LOGD(TAG, "Thermostat PID Controller daylight write_action: %.3f, set_val: %.3f, att_max: %.3f", state, set_val, att_max);
              float brightness = state;
              if (state > att_max) {
                float max_ratio = (set_val-1.0)*0.1;
                float att_ratio = (1.0-max_ratio)*att_max;
                brightness = (att_ratio + max_ratio)*id(twilight_attenuation);
                ESP_LOGD(TAG, "state>att_max. (%.2f%+.2f)*%.2f => brightness: %.2f", att_ratio, max_ratio, id(twilight_attenuation), brightness);
              }
              else if (state < att_min) {
                brightness = att_min;
                ESP_LOGD(TAG, "state<att_min (%.2f) => brightness: %.2f", att_min, brightness);
              }
              auto daylight = id(day_light).make_call();
              daylight.set_transition_length(30000);
              daylight.set_brightness(brightness);
              daylight.perform();
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

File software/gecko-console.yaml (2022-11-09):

esphome:
  name: geckoconsole
  platform: ESP32
  board: nodemcu-32s
  # includes:
  #   - custom_components/vcnl4040/vcnl4040.h
  # libraries:
  #  - "Adafruit BusIO@^1.11.1"
  #  - "Adafruit VCNL4040@^1.0.1"
  on_boot:
    priority: 250
    then:
      - sensor.rotary_encoder.set_value:
          id: rotary_dial
          value: 0
      - light.turn_on:
          id: rgb_leds
          red: 28%
          green: 28%
          blue: 28%
      - binary_sensor.template.publish:
          id: api_connected
          state: OFF
      - wait_until:
          api.connected
      - binary_sensor.template.publish:
          id: api_connected
          state: ON
      - lambda: |-
            id(rtttlplayer).play("Turn_on:d=32,o=6,b=150:c,e,g,c7");

  includes:
    - custom_components/gecko_common.h
    - custom_components/gecko_console.h

wifi:
  ssid: !secret wifi_ssid
  password: !secret wifi_password

  # Enable fallback hotspot (captive portal) in case wifi connection fails
  ap:
    ssid: "Geckocontrol Fallback Hotspot"
    password: !secret fallback_password

# Enable logging
logger:
  level: DEBUG

# Enable Home Assistant API
api:
  services:
    - service: play_rtttl
      variables:
        song_str: string
      then:
        - rtttl.play:
            rtttl: !lambda 'return song_str;'
    - service: mhz19_calibrate_zero
      then:
        - mhz19.calibrate_zero: co2_sensor

ota:

substitutions:
  menuSize: '7'

globals:
# Wait indicator
  - id: wi
    type: unsigned char
    initial_value: '0'

# Blank screen
  - id: s_blank
    type: bool
    initial_value: 'false'

# Menu helpers
  - id: menu_current_node
    type: unsigned char
    initial_value: '0'

  - id: menu_current_label
    type: char *

  - id: menu_current_value
    type: float

  - id: menu_current_percentage
    type: float

  - id: menu_target_value
    type: float

  - id: menu_weather_value
    type: float

  - id: menu_no_hass_updates
    type: bool
    initial_value: 'false'

    # subpage_t
  - id: menu_subpage
    type: unsigned char
    initial_value: '0'

  - id: menu_labels
    type: char * [${menuSize}]
    initial_value: '{"Overview","Thermostat","Hygrostat","CO2 LEDs","Scenic Light","Fogger","Rain"}'

  - id: menu_units
    type: char * [${menuSize}]
    initial_value: '{"","°C","%","","HSV","\U0000F67E","\U0000F683"}'

  # function_t
  - id: menu_functions
    type: unsigned char[${menuSize}]
    initial_value: '{0,FUNC_CLIMATE,FUNC_CLIMATE,FUNC_SLIDER,FUNC_COLORPICKER,FUNC_BUTTON,FUNC_BUTTON}'

    # The range maximum value
  - id: menu_rotary_ticks
    type: int [${menuSize}]
    initial_value: '{4,0,50,50,COLORPICKER_V_TICKS,1,1}'

  - id: menu_increment
    type: float [${menuSize}]
    initial_value: '{0,0.5,2.,2.,5.12,0,0}'

  - id: thermostat_diff
    type: float

  - id: hygrostat_diff
    type: float

  - id: previous_hue
    type: int
    initial_value: '0'

  - id: send_code
    type: std::string
    initial_value: ''
  - id: last_fan_direction
    type: bool
    initial_value: 'false'
  - id: codemap
    type: std::map<std::string, std::string>
    initial_value: '{
      {"stop",    "000001111101"},
      {"reverse", "000001111011"},
      {"light",   "000001111110"},
      {"button_released", "000001111111"}
      }'
  - id: speed_codes
    type: std::array<std::string, 7>
    initial_value: '{
      "000001111101", /* stop     */
      "000001110101", /* speed 1  */
      "000001110101", /* speed 2  */
      "000001101111", /* speed 3  */
      "000001100111", /* speed 4  */
      "000001011101", /* speed 5  */
      "000001011111"  /* speed 6  */
      }'
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

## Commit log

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2021-02-07 PCB: Add USB-C Port, Add BME280 Port
    [Geckocontroller.sch]
2021-02-07 Schema: Switch CP2104->CP2102 USB Interface
    [Geckocontroller.sch]
2021-02-07 Schema: RGB MOSFET Gate Pulldowns, Fix DS Pullups
    [Geckocontroller.sch]
2021-02-07 Schema: ADD SPI Header
    [Geckocontroller.sch]
2021-02-07 Schema: Use SSRs instead of mechanical relays
    [Geckocontroller.sch]
2021-02-07 Schema: Use ACT4088 Buck instead
    [Geckocontroller.sch]
2021-02-07 Schema: Set footprints of all components
    [Geckocontroller.sch]
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2021-02-09 Schema: Add HX711 load cell input + PWM fan connector
    [Geckocontroller.sch]
2021-02-09 PCB: Add HX711 load cell input + PWM fan connector
    [Geckocontroller.kicad_pcb]
2021-02-09 Schema: Add I2C pullups, fix a few footprints
    [Geckocontroller.sch]
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2021-02-10 Schema: Calculate feedback and volt.div. resistors for Buck and HX711
    [Geckocontroller.sch]
2021-02-10 PCB: More GND planes & vias, work on silkscreen inscriptions
    [Geckocontroller.kicad_pcb]
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2021-02-10 Schema+PCB: Switch GPIOs, add HX711 enable jumper
    * GPIO34 can only be used as input,
    so switch HX_CLK and FAN_SIG.
    [Geckocontroller.kicad_pcb, Geckocontroller.sch]
2021-02-11 Schema+PCB: Fix a few ERC issues, add warning symbols + QR Code
    Mark unconnected Pins with X's, set WAGO pins to passive
    [Geckocontroller.kicad_pcb, Geckocontroller.sch]
2021-02-12 Schema+PCB: Switch CP2102 with QFN28 version, add another Switch
    [Geckocontroller.kicad_pcb, Geckocontroller.sch]
2021-02-14 PCB: Add Repairfox and Purple Gecko silkscreen prints
    Schema: move graphical boxes around a bit
    [Geckocontroller.kicad_pcb, Geckocontroller.sch]
2021-02-14 hardware: Move kicad project into subfolder, add libraries and footprints
    [Geckocontroller.kicad_pcb, Geckocontroller.sch]
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2021-02-21 PCB: Change mounting holes
    Made to fit a BOPLA ET-223 case
    [Geckocontroller.kicad_pcb]
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2021-03-04 PCB: Remove pass marks
    They caused the screw holes to be fabriacted incorrectly at Aisler
    [Geckocontroller.kicad_pcb]
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2021-03-07 Hardware (Schema+PCB): Fix CP2102 power, optimize positionings
    [Geckocontroller.kicad_pcb, Geckocontroller.sch]
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2021-04-10 hardware: Add S8050 & S8550 symbols with fixed pinout
    Fixes auto programming and HX711 Load Cell AVDD
    [Geckocontroller.kicad_pcb, Geckocontroller.sch]
2021-04-10 hardware: Add pullup R for Fan Tacho
    GPIO35 doesn't seem to have in internal pullup resistor -
    fixes fan tacho measurement
    [Geckocontroller.kicad_pcb, Geckocontroller.sch]
2021-04-11 hardware: Improve Zero-Cross Detection circuit
    Thanks to Patagona and LeoDJ!
    [Geckocontroller.kicad_pcb, Geckocontroller.sch]
2021-04-11 hardware: Change footprint of optocoupler
    use a wider version, make it easier to solder
    [Geckocontroller.kicad_pcb, Geckocontroller.sch]
2021-04-11 software: Add HX711 & Fan PWM+Tacho, fix dimmer+BME parameters
    [gecko.yaml]
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2021-04-12 Schema: Add Fan PWM integrator and MOSFET switch
    [Geckocontroller.sch]
2021-04-12 PCB: Implement Fan PWM switch / rearrange modules
    [Geckocontroller.kicad_pcb]
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2021-04-13 hardware: wire GPIO12 to addon header, layout improvements
    * add 6-pin UART header
    * new, larger OSHW logo
    * new, smaller solder jumper for HX711
    * switch RGB-LED & I2C modules and respective part numbers
    * renumber some USB programmer parts
    * improve silkscreen inscriptions
    [Geckocontroller.kicad_pcb, Geckocontroller.sch]
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2021-04-13 Schema: Replace "rescued" symbols with standard library counterparts
    no functional changes
    [Geckocontroller.sch]
2021-04-14 PCB: Move around modules and masks a little more
    No functional changes
    [Geckocontroller.kicad_pcb]
2021-04-14 PCB: Add Smol Gecko Footprint, add silkscreen logos
    Commissioned for production with Aisler on 2021-04-15
    [Geckocontroller.kicad_pcb]
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2021-04-15 PCB: Flip L101 silkscreen label
    [Geckocontroller.kicad_pcb]
2021-04-16 Schema: Set data fields, use CP symbol for C11, renum R2, re-plot PDF
    [Geckocontroller.sch]
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2021-04-25 Hardware: Clean relay lib, change footprints
    * wider optocoupler width (move insulation edge accordingly)
    * handsolderable SOD-323 footprint
    [Geckocontroller.kicad_pcb, Geckocontroller.sch]
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2021-04-26 Software: Make effects accessible through drop-down menu (WIP)
    * lightning effect doesn't work yet
    [gecko.yaml]
2021-04-26 PCB: Move mounting holes a little bit to the center
    [Geckocontroller.kicad_pcb]
2021-04-27 Software: Fix lightning effect
    [gecko.yaml]
2021-04-27 Software: Work on sunset+sunrise effects (WIP)
    * added own header which holds the common LUT
    * problem is still: effect loop doesn't quit
    [gecko.yaml]
2021-04-27 Software: Fix stopping of sunrise + sunset effects
    [gecko.yaml]
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2021-05-06 Console Schema: Use linear regulator, add buzzer & RGB
    [Geckoconsole.sch]
2021-05-06 Console Schema: Renum all parts, add not-connected markers
    [Geckoconsole.sch]
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2021-05-09 Console Hardware: Add Extension header, PCB silkscreen labels
    [Geckoconsole.kicad_pcb, Geckoconsole.sch]
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2021-05-10 Console Schema+PCB: Add pull-up resistors for rotary encoder
    [Geckoconsole.kicad_pcb, Geckoconsole.sch]
2021-05-12 Console Software: Add more periphery
    * UART
    * MH-Z19
    * Rotary Encoder w/ button
    * Buzzer
    * Status LED
    [gecko-console.yaml]
2021-05-13 Controller PCB: Fix typo
    [Geckocontroller.kicad_pcb]
2021-05-14 Controller Software: Dallas properties
    * fix substrate sensor address
    * comment out absent heatbed sensor
    * increase interval (ease dimmer flicker)
    [gecko.yaml]
2021-05-15 Controller Software: Rain Pump / Humidity
    fixes "let it rain" button
    * change from slow_pwm to GPIO
    * comment out humidity PWM
    [gecko.yaml]
2021-05-16 Controller Software: Heatbed control
    * fix typo
    * comment out PID and climate control for heatbed (still missing)
    [gecko.yaml]
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2021-05-25 Console Schema: Add voltage-drop diode for WS2812 (for level shifting)
    [Geckoconsole.sch]
2021-05-25 Console PCB: add proximity sensor and level shifting
    * Add "break-out" daughterboard for VCNL4040 proximity sensor
    * Add diode for WS2812 level shifting
    [Geckoconsole.kicad_pcb]
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2021-05-30 Controller Software: Filter out HX711 glitches
    [gecko.yaml]
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2022-01-09 Revert "Software: Simulate Dusk & Dawn fog"
    This reverts commit ce332701778ea3d743121ee31483ae182778a84e.
    [gecko.yaml]
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2022-01-10 Software: Use mean value from ceiling+ground hygrometer as combined humidity
    * instead of using the highest of the both
    * also fix unit of measurement to %
    [gecko.yaml]
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2022-01-19 Software: Mirror location coordinates to northern hemisphere (Workaround)
    [gecko.yaml]
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2022-01-25 Console Hardware: Fix DRC problems (unconnected traces etc.)
    [Geckoconsole.kicad_pcb, Geckoconsole.kicad_sch]
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2022-01-27 Console PCB: Make ready for fab
    * rename layers according to Aisler Gerber specs
    * Silkscreen project lable
    * break-off-PCB drills
    [Geckoconsole.kicad_pcb]
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2022-01-30 Software: Fix RGB LED (PWM channel conflict)
    [gecko.yaml]
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2022-01-30 Software: Use intermediary template switch for fogger
    * fixes manual humidifier button
    [gecko.yaml]
2022-01-30 Software: Fix fan output from slider & climate controllers
    Controllers don't directly write to the fan output now, instead they each got their
    own template output where it's checked whether the controller is actually active
    and has priority to change the fan state, and then write this to the fan_speed slider
    instead of the actual physical output. this way the state is reflected in the HASS GUI
    [gecko.yaml]
2022-01-31 Software: Explicitely set LEDC PWM channels (fix blue tint)
    [gecko.yaml]
2022-01-31 Software: Reduce noise in scale sensor
    * drop negative (glitchy) values
    * increase delta
    [gecko.yaml]
2022-01-31 Software: Rework daylight controller
    * use different quantifiers for positive/negative attenuation
    [gecko.yaml]
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2022-02-02 Software: Refactor Thermostat daylight write_action
    * will now account for skycond and twilight
    * new linearizer regarding actual control value (>1.0) which
    applies weighted attenuation
    * increase transition duration to 30s
    Fixup: correct brightness on sky condition update
    [gecko.yaml]
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2022-02-04 Software: Implement WeightedFanOutput class
    * move stuff from GeckoCustomComponent
    * rename humiditiy_controller -> hygrostat
    * fix little SunDayLightEffect glitch
    [gecko.yaml]
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2022-02-08 Software: Fix windspeed logic error
    * clamp to humidity control minimum
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2022-02-11 custom_components: Rework value sinks
    * instead of having 4 discrete FloatOutput sinks,
    have the main MultiFan act as a dummysink for all of the PID controllers
2022-02-11 custom_components: Add fan traits to MultiFan
    * show speed slider in HASS
    * "Oscillating" switch turn off and on automatic speed processing
2022-02-20 Hardware (Schema+PCB): Change ZC Resistors
    * use 1206 instead of 0805 footprints
    * explicitely rate 400V+
    [Geckocontroller.kicad_pcb, Geckocontroller.kicad_sch]
2022-02-24 Console Schema: Fix missing VCC connection on rotary enc
    [Geckoconsole.kicad_sch]
2022-02-24 Console PCB: Fix missing VCC connection on rotary enc
    [Geckoconsole.kicad_pcb]
2022-02-27 Software Console: Add RTTTL buzzer playback service
    [gecko-console.yaml]
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2022-02-27 Schema Console: Additional Button2 for Navigation, remove R81
    [Geckoconsole.kicad_sch]
2022-02-27 Schema Console: Remove R55 (Fix Reset Button), graphical improvements
    [Geckoconsole.kicad_sch]
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2022-02-28 Software Console: Fix rotary encoder jumpiness
    * by implementing a HASS updater timeout
    * also make encoder sensor internal
    [gecko-console.yaml]
2022-03-01 Software Console: Big time Work in Progress on Menu
    * replace screensaver with overview
    * remove entire submenu stuff
    * add subpages with graph plots
    * this broke the climate controls (wrong angle!)
    [gecko-console.yaml]
2022-03-02 custom_components: Fix DisplayBuffer:gauge sector color for 50.0% case
2022-03-02 Software Console: Fix Menu & Climate Controller
    [gecko-console.yaml]
2022-03-02 Software Console: Refactor Colors, add CO2 to Overview, fix brightness slider
    [gecko-console.yaml]
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2022-03-04 Software Console: Fix jumping climate controls (ignore HASS updates properly)
    * also account for possible rounding errors in rotary value range calculation
    [gecko-console.yaml]
2022-03-04 Software Console: Clamp CO2 colors
    Fix incorrect Overview background on very low values
    [gecko-console.yaml]
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2022-03-05 Software Console: Fix Rain & Fox buttons
    [gecko-console.yaml]
2022-03-06 Hardware Console: Start with HW Revision 2
    * include 2nd navigation button
    * move USB-C interface onto separate daughter board
    * hide VCNL4040 parts from PCB
    * turn ESP32 180°
    * move LCD pin header to top of board
    * switch a few GPIOs
    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
    [Geckoconsole.kicad_pcb, Geckoconsole.kicad_sch]
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2022-03-07 Hardware Console: Improve Layout: DRC, Mouse Bites, placement, silkscreen
    [Geckoconsole.kicad_pcb, Geckoconsole.kicad_sch]
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2022-03-08 PCB Console: Flip USB daugherboard, switch rotary encoder to SMD type
    [Geckoconsole.kicad_pcb]
2022-03-08 Hardware Console: Route USB daughter board & some more GPIO shuffling
    [Geckoconsole.kicad_pcb, Geckoconsole.kicad_sch]
2022-03-09 Software Console: Replace menu function numbers with cleartext enum
    [gecko-console.yaml]
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2022-03-12 Software Console: Move CO2 warning buzzer playback into script
    [gecko-console.yaml]
2022-03-13 Software Console: Fix Overview diff (call correct script on weather values)
    [gecko-console.yaml]
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2022-03-14 Software Console: Fix weather/setpoint update actions
    * don't set inhibitor variable on HASS updates, only on rotary action
    [gecko-console.yaml]
2022-03-14 Software Console: Improve RTTTL playback
    * use on_prepare_playback automation callback to increase the display
    update interval to 15s during RTTTL playback for correct timing
    * use on_playback_finished to set the display update interval back to 500ms
    [gecko-console.yaml]
2022-03-14 Revert "custom_components: implement ST7789V::set_update_interval"
    This reverts commit 9629f84fa06a4520d703afa0182800c10bdcaa25.
    [gecko-console.yaml]
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2022-04-05 Hardware Library: Add Footprint for Buzzer FUET 9650B
    * polarity marking
    * larger pads for improved hand-solderability
2022-04-05 Software Console: Fix resolution for new rotary encoder
    [gecko-console.yaml]
2022-04-05 Hardware Console: Fix Encoder button (missing GND wire)
    [Geckoconsole.kicad_pcb, Geckoconsole.kicad_sch]
2022-04-05 Hardware Console: Use new FUET Buzzer in schematic and PCB
    [Geckoconsole.kicad_pcb, Geckoconsole.kicad_sch]
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2022-11-09 Software Console: Fix indentation on global vars
    [gecko-console.yaml]
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

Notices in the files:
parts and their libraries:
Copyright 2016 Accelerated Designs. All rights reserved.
